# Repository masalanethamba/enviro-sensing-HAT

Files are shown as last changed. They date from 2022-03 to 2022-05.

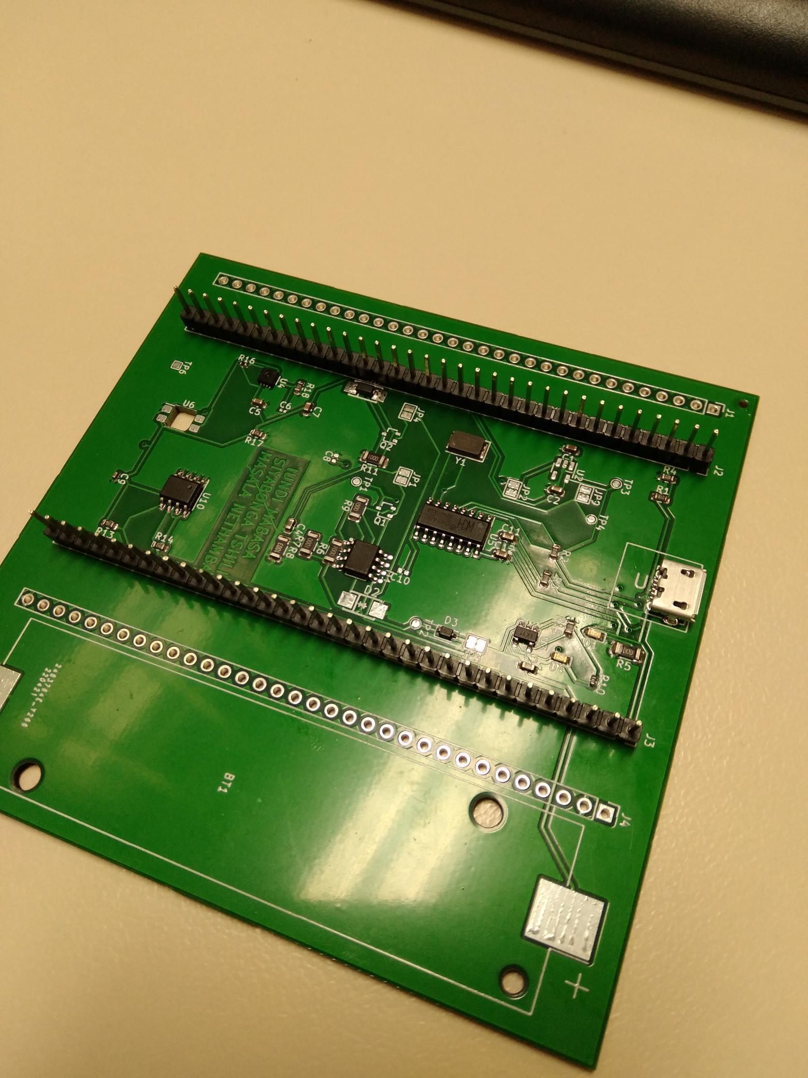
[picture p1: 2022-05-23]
PCB/PCB1.png

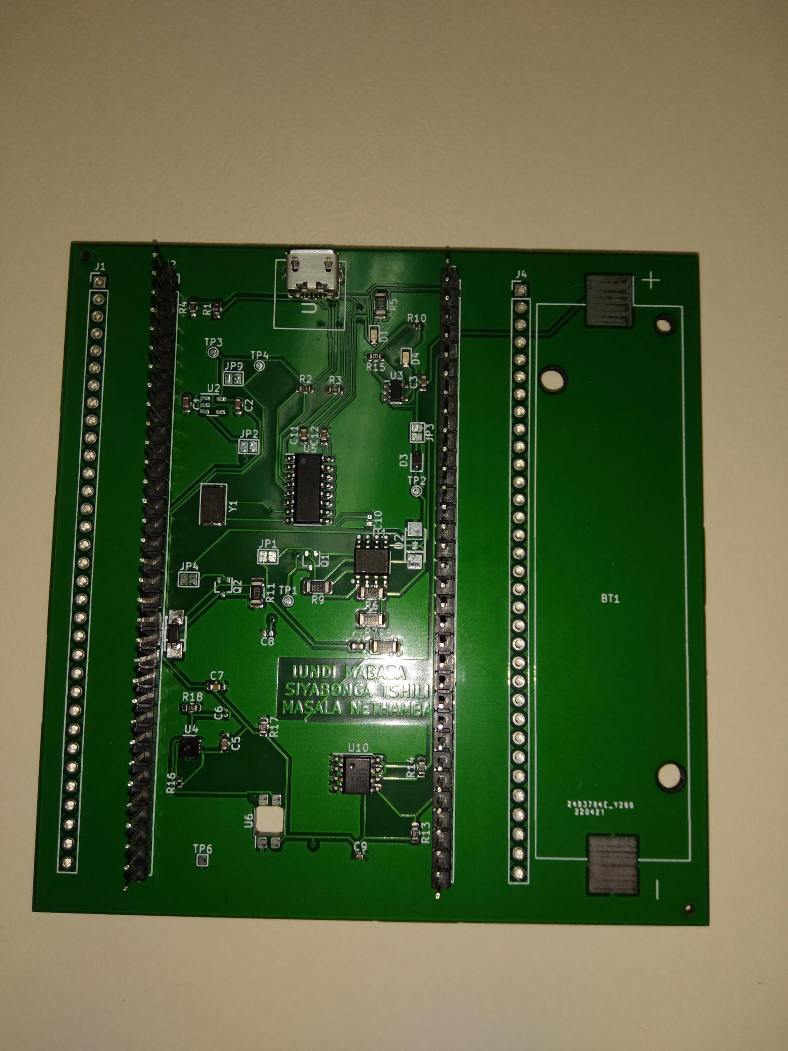
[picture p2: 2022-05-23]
PCB/PCB3.png

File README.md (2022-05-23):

**GROUP 34**

**Description**

TheTemperature-Light sensor is a system that monitors and records
the temperature and light of a room or any place under consideration such that if the
temperature and the light are higher than required, the system displays it on the
computer. Similarly, if the temperature and the light are lower, the system displays it.
This System can also be connected to external Temperature/Light controllers.
Temperature/Light controller can be manual or automatic. The former requires full
human intervention to operate, while the latter requires little or not at all.
Furthermore, most temperature/light controller and related systems designed make
used of discrete components design such as timers, counters, decoder drivers and
thermistor temperature sensor and some use microcontrollers with external analogue
to digital converter (ADC) which is recommended for this system.
This system is powerful and very easy-to-program. It has 33-pins, and it has a
memory of 256-KB I2C of EEPROM data memory, self-programming.
Operating voltage range between 2V to 5V

**Getting Started with Temperature Sensor version5.1 and STM32CubeID**

**Introduction**
_________________________________________________________________________________

In this simple getting started how to document, we will be building a simple STM32CUBEID project (code) on a simple Temperature and Humidity Sensor uHAT. At its simplest/basic level the whole process of deploying  a code to the Temperature and Humidity Sensor PCB Version 5.1 consists of two “must do'' steps:

→ You would need to set your Temperature and Humidity Sensor with Group34OS, the  host OS which is responsible for  communication with the UCTCloud and also runs the core operations of the device

→  You need to also push your STM32CUBEID project image builder, which is responsible for pulling in all the important   
   dependencies and makes a container image for your fleet.
   
A completion of these steps implies that your Temperature and humidity Sensor Ver 5.1 will start to download the container image, begin your application, and start sending logs to your Group34 dashboard. This has got you at least a step towards success!

**What will you need?**
__________________________________________________________________________________
Hardware:

→ A Temperature and Humidity Sensor uHAT Ver5.1. You can also visit or GitHub repo and check out similar or related
                models.
                
→  18650-5V Li-ion battery for Power supply(optional) .

→ A simple micro USB mini cable for access to the CH340G transceiver and debugging

→ The micro USB can also be used for power supply.

→ Female connectors 

→ A syringe for water drops to acknowledge and appreciate the functionality of the sensors.

→ The STM32F051 UCT discovery board for the Cortex-M0 microcontroller interfacing.

→ A Group34 account/ link

→ Github account   

Software :
    →  STM32CUBEIDE
    
     →   Atollic and C are also alternatives but STM32CUBE IDE are strongly recommended

Setting up the Temperature and Humidity Sensor
 _________________________________________________________

Step1: Getting the overall view of the board

The overall view of the PCB is pretty much self explanatory, with the USB connector at the top and extended layer for the battery holder. On either side of the board there are 33x2 connectors, the first ones are female connectors  for mounting the uHAT on the UCT STM32F051 discovery board. The second are for debugging the board itself in a case of damaged pins. In Between the connectors there is a range of peripherals which include the two analog and digital sensors.

Overall View



Step2: Soldier and connect the female connectors on the board, These female connectors enable the PCB to be logged on the STM32f051 discovery board.
If soldered and connected correctly you have something like this: 



Step 3: Plugging the board to a power source.

This step is a 2 in 1 where we will be powering the PCB using the micro USB and deploying a code for the board to be able send information to the microcontroller.

Plugged board:



OPTIONAL:
The uHAT uses two sources of power, the USB and the Battery. You can also use the 5V Li-ion battery(18650)  but this step is optional because you would still need to connect the USB cable to send and receive information to the microcontroller. 

DEPLOYING THE CODE
________________________________________________________________________________________________________

This section covers the codes that are supposed to be written on the STM32CUBE IDE which sends this information (code) to the microcontroller, 

Step4 : Run the STM32CUBE IDE
Open and run the Stm32cube ide and copy and paste the following code on the references.
1.  



2.



3.



CONGRATULATIONS🥳, the Temperature and Humidity sensor is now fully functional, you can proceed to test the functionality of the board, we are looking forward to seeing you on version 6.

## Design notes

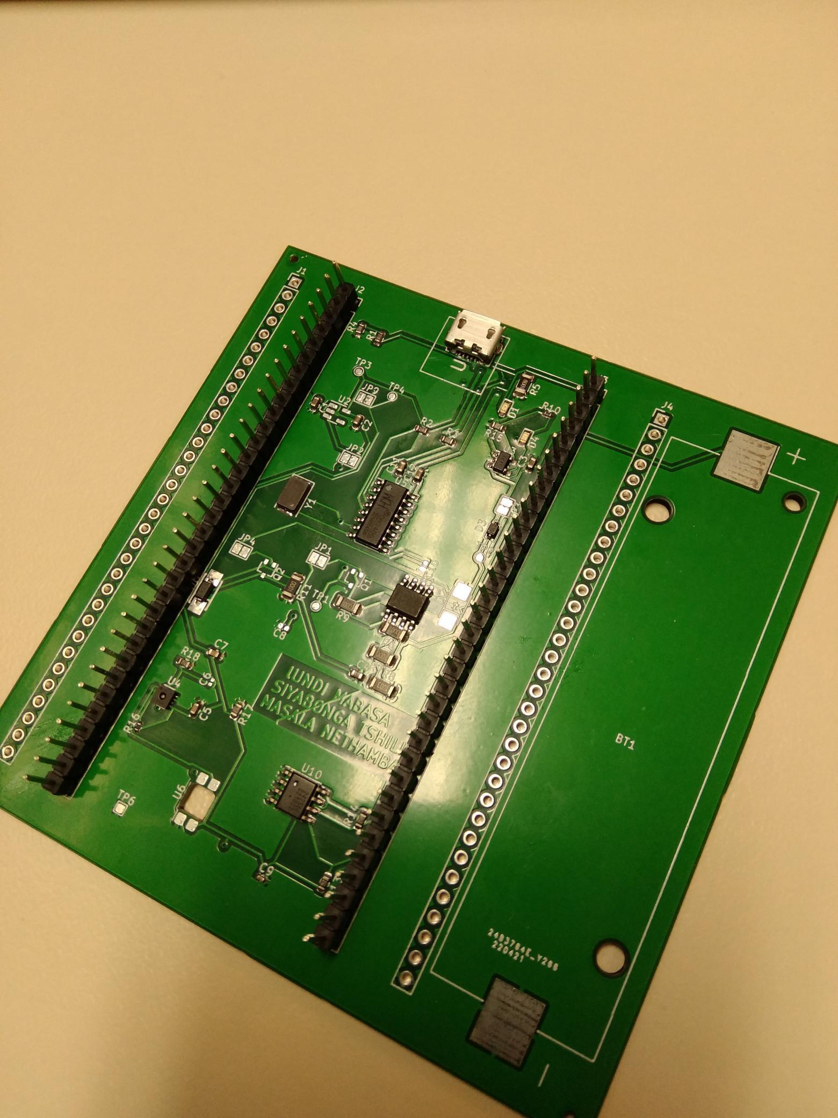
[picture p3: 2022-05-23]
PCB/PCB2.png

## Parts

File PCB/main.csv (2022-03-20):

Source: | C:\Users\masal\OneDrive\Desktop\Design Projext\Source Code\Source Code\PCB\main\main.kicad_sch
Date: | 2022/03/20 23:28:56
Tool: | Eeschema (6.0.2)
Generator: | C:\Program Files\KiCad\6.0\bin\scripting\plugins/bom_csv_grouped_by_value_with_fp.py
Component Count: | 44
Ref | Qnty | Value | Cmp name | Footprint | Description | Vendor
C1, C8, | 2 | 10nF | C |  | Unpolarized capacitor
C2, | 1 | 10u | C_Small |  | Unpolarized capacitor, small symbol
C3, C4, C7, | 3 | 10nf | C |  | Unpolarized capacitor
C5, C6, | 2 | 0.1uF | C |  | Unpolarized capacitor
D1, D3, D4, | 3 | LED_Small | LED_Small |  | Light emitting diode, small symbol
D2, | 1 | D_Zener | D_Zener |  | Zener diode
D5, | 1 | Blue | LED |  | Light emitting diode
J1, J4, | 2 | Conn_01x33_Female | Conn_01x33_Female | Connector_PinHeader_2.54mm:PinHeader_1x33_P2.54mm_Vertical | Generic connector, single row, 01x33, script generated (kicad-library-utils/schlib/autogen/connector/)
J2, J3, | 2 | Conn_01x33_Female | Conn_01x33_Female | Connector_PinSocket_2.54mm:PinSocket_1x33_P2.54mm_Vertical | Generic connector, single row, 01x33, script generated (kicad-library-utils/schlib/autogen/connector/)
J5, | 1 | USB_B_Micro | USB_B_Micro |  | USB Micro Type B connector
M1, M2, | 2 | MPMOS | MPMOS |  | P-channel MOSFET symbol for simulation only
R1, R2, R3, R4, R6, R7, R8, R10, R11, | 9 | 1K | R |  | Resistor
R5, | 1 | 100 | R_Small |  | Resistor, small symbol
R9, | 1 | 4.7K | R |  | Resistor
R12, | 1 | R | R |  | Resistor
R13, R14, | 2 | 10K | R |  | Resistor
U1, | 1 | MC34673 | MC34673 | Package_DFN_QFN:DFN-8-1EP_3x2mm_P0.5mm_EP1.75x1.45mm | High Input Voltage 1.2A Charger for Single-cell Li-Ion Batteries, UDFN-8
U2, | 1 | ADG417BN | ADG417BN | Package_DIP:DIP-8_W7.62mm | Single SPST Monolithic LCÂ²MOS Analog Switch, normally OFF, 25Ohm Ron, DIP-8
U3, | 1 | HT75xx-1-SOT89 | HT75xx-1-SOT89 | Package_TO_SOT_SMD:SOT-89-3 | 100mA Low Dropout Voltage Regulator, Fixed Output, SOT89
U4, | 1 | FT232RL | FT232RL | Package_SO:SSOP-28_5.3x10.2mm_P0.65mm | USB to Serial Interface, SSOP-28
U5, | 1 | TLV172IDCK | TLV172IDCK | Package_TO_SOT_SMD:SOT-353_SC-70-5 | Low-power Operational Amplifier, SOT-353
U6, | 1 | BME280 | BME280 | Package_LGA:Bosch_LGA-8_2.5x2.5mm_P0.65mm_ClockwisePinNumbering | 3-in-1 sensor, humidity, pressure, temperature, I2C and SPI interface, 1.71-3.6V, LGA-8
U7, | 1 | TSL2550D | TSL2550D | Package_SO:SOIC-8_3.9x4.9mm_P1.27mm | Ambient Light Sensor with SMbus Interface, SO-8 interface
U8, | 1 | TC1047AxNB | TC1047AxNB | Package_TO_SOT_SMD:SOT-23 | Precision Temperature-to-Voltage Converter, 10mV/ÂºC, -40ÂºC to +125ÂºC, Â±2.0ÂºC (max), 2.5V to 5.5V, SOT-23
U9, | 1 | CH330N | CH330N | Package_SO:SOIC-8_3.9x4.9mm_P1.27mm | USB serial converter, UART, SOIC-8
U10, | 1 | CAT24C256 | CAT24C256 |  | 256 kb CMOS Serial EEPROM, DIP-8/SOIC-8/TSSOP-8/DFN-8

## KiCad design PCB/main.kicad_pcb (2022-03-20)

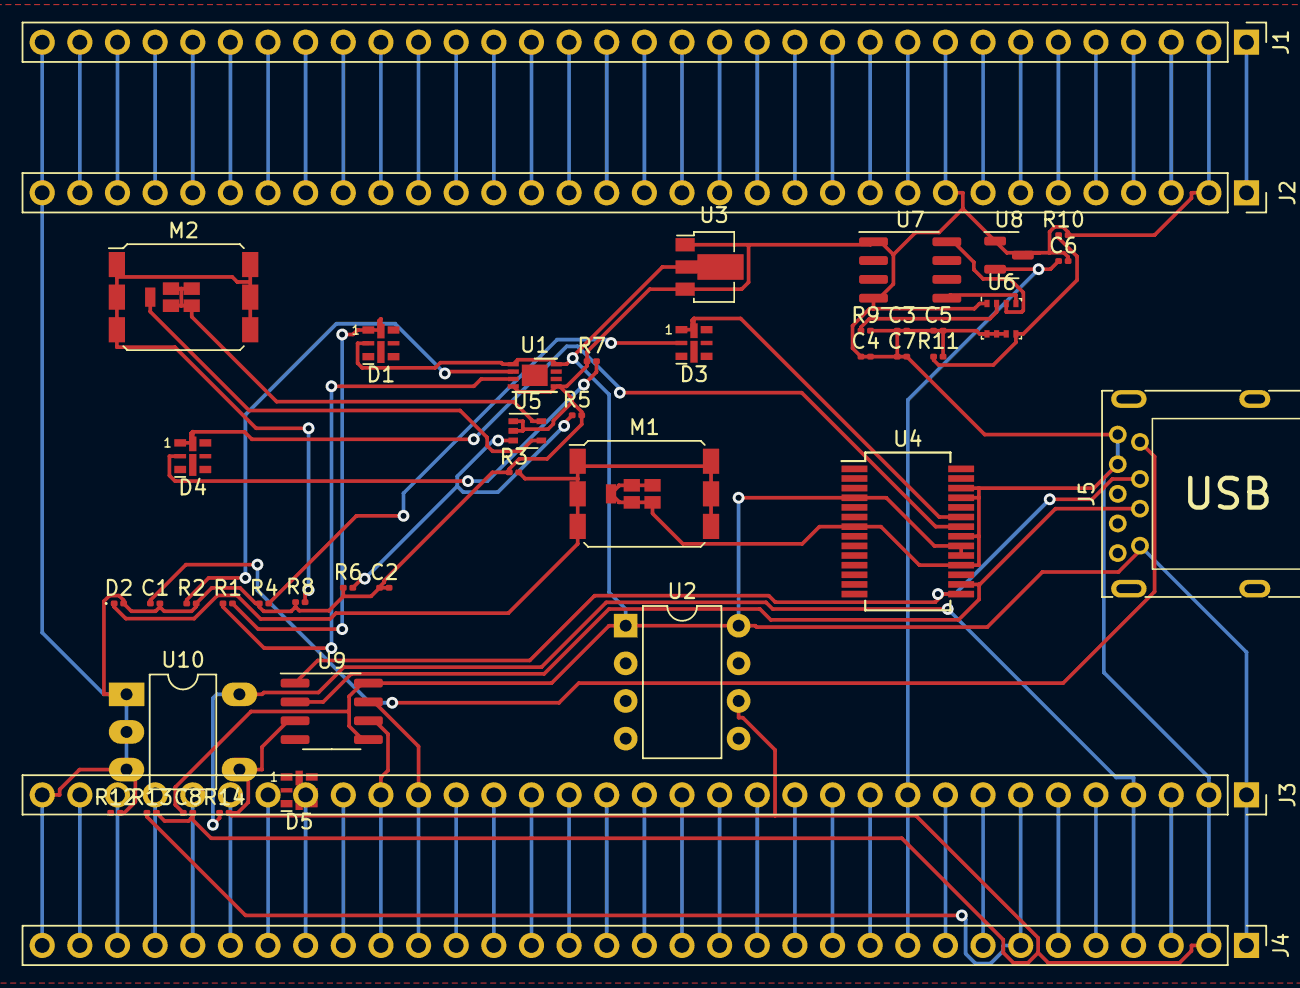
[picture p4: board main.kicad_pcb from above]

Board: 2 copper layers, 44 parts (0 on the bottom side), 82 nets.

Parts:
C1, C8: 10nF; C_0201_0603Metric
C2: 10u; C_0201_0603Metric
C3, C4, C7: 10nf; C_0201_0603Metric
C5, C6: 0.1uF; C_0201_0603Metric
D1, D3, D4: LED_Small; LED-APA102-2020
D2: D_Zener; D_0201_0603Metric
D5: Blue; LED-APA102-2020
J1, J4: Conn_01x33_Female; PinHeader_1x33_P2.54mm_Vertical
J2, J3: Conn_01x33_Female; PinSocket_1x33_P2.54mm_Vertical
J5: USB_B_Micro; USB3_A_Molex_48393-001
M1, M2: MPMOS; DirectFET_L4
R1, R2, R3, R4, R6, R7, R8, R10, R11: 1K; R_0201_0603Metric
R5: 100; R_0201_0603Metric
R9: 4.7K; R_0201_0603Metric
R12: R; R_0201_0603Metric
R13, R14: 10K; R_0201_0603Metric
U1: MC34673; DFN-8-1EP_3x2mm_P0.5mm_EP1.75x1.45mm
U2: ADG417BN; DIP-8_W7.62mm
U3: HT75xx-1-SOT89; SOT-89-3
U4: FT232RL; SSOP-28_5.3x10.2mm_P0.65mm
U5: TLV172IDCK; SOT-353_SC-70-5
U6: BME280; Bosch_LGA-8_2.5x2.5mm_P0.65mm_ClockwisePinNumbering
U7: TSL2550D; SOIC-8_3.9x4.9mm_P1.27mm
U8: TC1047AxNB; SOT-23
U9: CH330N; SOIC-8_3.9x4.9mm_P1.27mm
U10: CAT24C256; DIP-5-6_W7.62mm_LongPads

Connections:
12C1_Clock: J3.4, J4.4, R14.1, U10.6 (SCL)
12C1_Data: J3.7, J4.7, R13.1
+3V0: J1.1, J2.1
+3V3: C1.2, C2.1, C2.2, C3.1, C3.2, C4.1, C4.2, C5.1, C5.2, C6.2, C7.1, C7.2, C8.2, D2.2 (A), J1.2, J1.9, J1.33, J2.2, J2.9, J2.33, J3.2, J3.33, J4.2, J4.33, J5.5 (GND), J5.6 (Shield), M1.2 (G), M1.3 (S), R2.2, R3.1, R4.1, R5.2, R6.1, R7.1, R8.1, R9.2, R10.2, R11.2, R12.2, R13.2, R14.2, U1.4 (~EN), U1.5 (GND), U2.6, U3.1 (GND), U3.3 (VOUT), U4.7 (GND), U4.18 (GND), U4.21 (GND), U4.25 (AGND), U4.26 (TEST), U5.1 (+), U5.2 (V-), U6.1 (GND), U6.6 (VDDIO), U6.7 (GND), U6.8 (VDD), U7.1 (VDD), U7.4 (GND), U8.1 (Vdd), U8.3 (GND), U9.3 (GND), U10.1 (A0), U10.2 (A1), U10.3 (A2), U10.4 (GND)
+5V: C8.1, D1.2 (A), D5.2 (A), J3.1, J4.1, J5.1 (VBUS), U1.1 (VIN), U1.8 (BAT), U2.1, U2.8, U3.2 (VIN), U4.4 (VCCIO), U4.19 (~RESET), U4.20 (VCC), U9.5 (VCC), U9.8 (V3)
/BOOT: J3.6, J4.6
/NRST: J1.10, J2.10
/PA0: J1.15, J2.15
/PA1: J1.16, J2.16
/PA2: J1.17, J2.17
/PA3: J1.18, J2.18
/PA4: J1.21, J2.21
/PA5: J1.22, J2.22
/PA6: J1.23, J2.23
/PA7: J1.24, J2.24
/PA8: J3.25, J4.25
/PA11: J3.22, J4.22
/PA12: J3.21, J4.21
/PA13: J3.20, J4.20
/PA14: J3.17, J4.17
/PA15: J3.16, J4.16
/PB0: J1.27, J2.27
/PB1: J1.28, J2.28
/PB2: J1.29, J2.29
/PB3: J3.11, J4.11
/PB5: J3.9, J4.9
/PB6: J3.8, J4.8
/PB9: J3.3, J4.3
/PB10: J1.30, J2.30
/PB11: J1.31, J2.31
/PB12: J1.32, J2.32
/PB13: J3.32, J4.32
/PB14: J3.31, J4.31
/PB15: J3.30, J4.30
/PC0: J1.11, J2.11
/PC1: J1.12, J2.12
/PC2: J1.13, J2.13
/PC3: J1.14, J2.14
/PC4: J1.25, J2.25
/PC5: J1.26, J2.26
/PC6: J3.29, J4.29
/PC7: J3.28, J4.28
/PC8: J3.27, J4.27
/PC9: J3.26, J4.26
/PC10: J3.15, J4.15
/PC11: J3.14, J4.14
/PC12: J3.13, J4.13
/PC13: J1.4, J2.4
/PC14: J1.5, J2.5
/PC15: J1.6, J2.6
/PD2: J3.12, J4.12
/PF0: J1.7, J2.7
/PF1: J1.8, J2.8
/PF4: J1.19, J2.19
/PF5: J1.20, J2.20
/PF6: J3.19, J4.19
/PF7: J3.18, J4.18
/VBAT: J1.3, J2.3
Anaolog_Out: C6.1, J3.10, J4.10, U8.2 (Vout)
I2C1_Data: U6.3 (SDI), U7.8 (DAT)
I2C2_Clock: U6.4 (SCK), U7.5 (CLK)
unnamed: C1.1, J5.4 (ID)
unnamed: D1.1 (K), R1.2
unnamed: D2.1 (K), M1.1 (D), R3.2
unnamed: D3.1 (K), U4.23 (CBUS0)
unnamed: D3.2 (A), R4.2
unnamed: D4.1 (K), U4.22 (CBUS1)
unnamed: D4.2 (A), R7.2
unnamed: D5.1 (K), R12.1
unnamed: M2.1 (D), R8.2
unnamed: M2.2 (G), U5.4
unnamed: M2.3 (S), U5.5 (V+)
unnamed: R1.1, U1.3 (~CHG)
unnamed: R2.1, U1.2 (~PPR)
unnamed: R5.1, R6.2, U5.3 (-)
unnamed: R9.1, U6.2 (CSB)
unnamed: R10.1, R11.1, U6.5 (SDO)
USART_RX: J3.23, J4.23, U9.7 (RXD)
USART_TX: J3.24, J4.24, U9.6 (TXD)
USB_D+: J5.3 (D+), U4.15 (USBD+), U9.1 (UD+)
USB_D-: J5.2 (D-), U4.16 (USBD-), U9.2 (UD-)
VDD: J3.5, J4.5

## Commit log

2022-03-20 Create CAD
2022-03-20 Create PCB
2022-03-20 Bills of Material for the modules individually and the combined main circuit
    [main.csv, microcontroller_interfacing.csv, power.csv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]
